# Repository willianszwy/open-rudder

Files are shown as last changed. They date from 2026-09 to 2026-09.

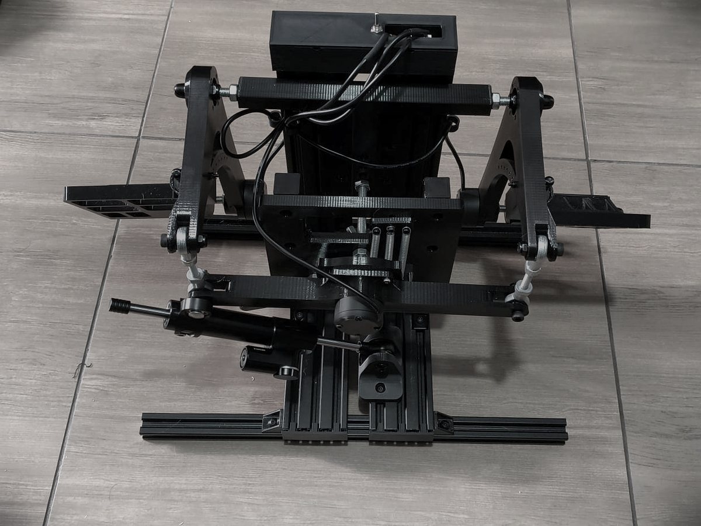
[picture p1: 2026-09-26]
fotos/pedal-cima.jpg

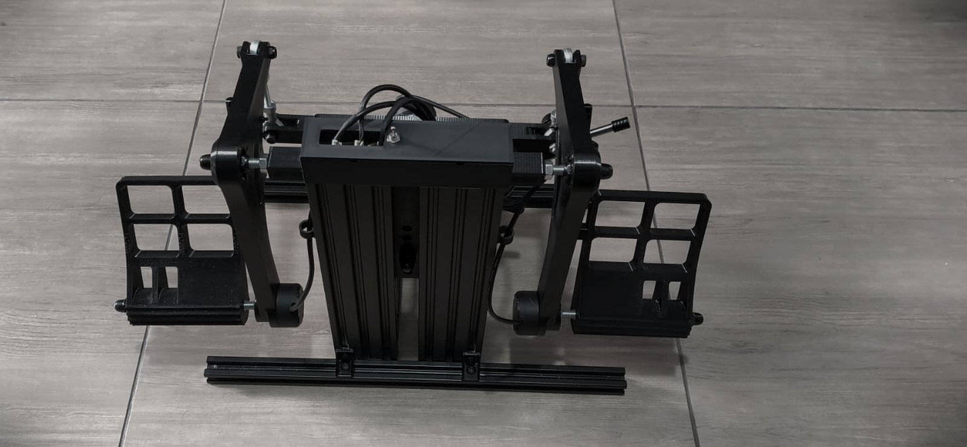
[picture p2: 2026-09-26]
fotos/pedal-frente.jpg

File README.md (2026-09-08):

# Open Rudder

Pedal de leme **pendular** para simulação de voo, com sensor magnético sem contato.
Eletrônica, firmware e calibrador abertos.

O ângulo é lido por um **AS5600** (Hall, 12 bits, absoluto) e um **Pro Micro** publica
o resultado como joystick USB HID — sem potenciômetro, sem contato, sem desgaste no
caminho do sinal.

**→ [Calibrador e esquemas](https://willianszwy.github.io/open-rudder/)** — roda no
navegador, sem instalar nada.

**Estado:** eixo do leme funcionando. Freios de biqueira implementados no firmware,
aguardando montagem mecânica.

## Eixos

| Eixo HID | Fonte | Faixa | Estado |
|---|---|---|---|
| **Rz** | leme | −16383 … +16383 | funcionando |
| **X** | freio de biqueira esquerdo | 0 … 4095 | firmware pronto, mecânica pendente |
| **Y** | freio de biqueira direito | 0 … 4095 | firmware pronto, mecânica pendente |

Rz é o eixo que DCS, MSFS e X-Plane reconhecem direto como leme.

## Arquivos

```
firmware/open_rudder/     firmware principal (leme + 2 freios, USB HID)
firmware/as5600_angle/    sketch mínimo de diagnóstico do sensor
web/calibrador.html       calibrador por Web Serial (Chrome/Edge)
hardware/ligacao.svg      diagrama de ligação
hardware/perfurada.svg    layout da placa perfurada (imprimível 1:1)
hardware/diagrama.html    as duas folhas acima, prontas para imprimir
```

## Eletrônica

O endereço I²C do AS5600 é **fixo em 0x36 e não é programável**, então os três sensores
não coexistem no mesmo barramento. Por isso o **TCA9548A**: cada sensor fica isolado em
um canal, e o firmware chaveia entre eles.

Diagrama de ligação

Detalhes de montagem, capacitores, cabeamento e o layout da placa estão em
`hardware/diagrama.html` — abra no navegador e imprima: a folha da perfurada sai em
tamanho real e serve de gabarito.

> **Tensão:** o AS5600 tem dois modos de alimentação — 5 V pelo pino VDD5V (LDO interno)
> ou 3,3 V pelo VDD3V3. Com módulos de 5 V, o barramento inteiro roda no VCC do Pro Micro
> e nenhum regulador é necessário. Confirme qual variante são os seus antes de ligar:
> num módulo de 3,3 V, 5 V ultrapassa o limite e queima.

### Lista de material (só a eletrônica)

| Item | Qtd | ~R$ |
|---|-----|-----|
| Pro Micro (ATmega32U4, USB HID nativo) | 1 | 35 |
| Módulo AS5600 | 3 | 75 |
| Ímã diametral Ø6×2,5 mm | 3 | 24 |
| Multiplexador I²C TCA9548A (módulo HW-617) | 1 | 12 |
| Placa perfurada 7×9 cm, conectores, cabo par trançado | — | 25 |
| **Total** | | **~R$ 170** |

O ímã tem que ser **diametral** (magnetizado de lado a lado, não axial), centrado no
eixo, a 0,5–3 mm da face marcada do chip.

## Firmware

Precisa da biblioteca [Joystick](https://github.com/MHeironimus/ArduinoJoystickLibrary)
(2.1.1+). Placa: Arduino Micro / Leonardo (ou SparkFun Pro Micro, se você tiver o pacote
instalado).

```bash
arduino-cli compile --fqbn arduino:avr:micro firmware/open_rudder
arduino-cli upload -p COM5 --fqbn arduino:avr:micro firmware/open_rudder
```

Como funciona:

- **Round-robin de 1 kHz** pelos canais do mux — 333 Hz por eixo, de sobra para um pedal.
- **Calibração por eixo na EEPROM**: zero, batentes, inversão, deadzone e expo.
- O zero é resolvido em coordenadas relativas com wrap em ±2048, então **o centro pode
  cair em qualquer ponto do giro** do ímã — não importa como o ímã ficou na montagem.
- **Filtro EMA** (α = 0,35) mata o jitter de ±1 count sem atraso perceptível.
- **Sem o TCA9548A ligado**, cai sozinho para o modo de 1 sensor (só o leme) — dá para
  montar por partes.

Com cabo longo até as biqueiras, se aparecer `sem resposta no eixo`, baixe `I2C_CLOCK`
para `100000` no topo do sketch.

## Calibração

Sem calibrar, o eixo não significa nada: o AS5600 mede 0–360° absolutos e o centro do
seu pedal cai num ponto arbitrário desse círculo.

1. Abra **https://willianszwy.github.io/open-rudder/** e clique em *Calibrador*.
2. **Conectar** e escolha a porta do Arduino.
3. Leme: Centro → Batente esquerdo → Batente direito. Freios: Repouso → Fundo.
4. **Gravar na EEPROM**.

A página mostra os três eixos ao vivo, o status dos ímãs (AGC) e onde o curso útil cai
no giro completo do sensor. Detalhes em `web/README.md`.

> A Web Serial API só funciona em **Chrome ou Edge** e em contexto seguro. O site é
> HTTPS, então serve; abrir o HTML direto pelo Explorer (`file://`) não. Para rodar
> offline, use o `web/servir.bat`, que sobe um servidor local.

## Mecânica

Arquitetura **pendular**: a barra do pedal gira sobre rolamentos e o **ímã diametral fica
na ponta da barra**, coaxial com o eixo de giro. O AS5600 fica fixo de frente para o ímã,
sem encostar em nada — o sensor não faz parte do caminho mecânico, só olha para ele.

O retorno é por **mola**: pisar comprime a mola, que devolve o pedal à posição inicial.
Enquanto você pisa, o AS5600 vai lendo o ângulo continuamente.

Três consequências práticas disso:

- **A posição de repouso da mola é o zero elétrico.** É ela que você captura no passo
  *Centro* da calibração. Se a mola ceder com o tempo, basta capturar o Centro de novo e
  regravar: os batentes são medidos em relação ao zero, então continuam válidos.
- **Alinhamento manda na linearidade.** O ímã precisa estar centrado no eixo de giro, e o
  chip centrado no ímã. Descentralização radial distorce o ângulo lido — e distorce de
  forma que a calibração de pontas não corrige, porque o erro varia ao longo do curso.
- **Distância ímã–chip entre 0,5 e 3 mm.** Confira pelo AGC no calibrador: perto do meio
  da escala é o ideal. Muito baixo significa ímã perto demais, sem margem para saturar.

Restrições que o sensor impõe ao projeto mecânico:

- **Freios:** mire **10–15° de curso** no pivô da biqueira. O AS5600 dá 0,088° por count,
  então 10° ≈ 115 counts — abaixo disso a dosagem fica granulada.
- **Leme:** o AS5600 entrega 4096 counts na volta inteira, então o curso útil é a fração
  do giro que o pedal realmente percorre. Para ±17°, são ~380 counts no curso total —
  equivalente a um potenciômetro de 9 bits. Suficiente, mas é o teto de resolução.

*A documentar:* curso real em graus, dimensões da barra, rolamentos e a mola de retorno.

## Licença

*A definir.*

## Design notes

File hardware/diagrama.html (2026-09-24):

# Open Rudder — diagrama de ligação

Pro Micro (ATmega32U4) · TCA9548A em 0x70 · 3× AS5600 em 0x36, um por canal

Diagrama de ligação: Pro Micro, TCA9548A e três AS5600

Notas de montagem

1. * Alimentação: 5 V direto do Pro Micro. O AS5600 tem dois modos — pelo pino VDD5V (4,5–5,5 V, com LDO interno) ou pelo VDD3V3 (3,0–3,6 V). Os módulos de 5 V rodam no VCC do Pro Micro sem regulador nenhum, e o TCA9548A aceita até 5,5 V. Só se os seus módulos forem da variante 3,3 V é que entra um AMS1117-3.3 alimentado pelo VCC — nesse caso 5 V passa dos 3,6 V do modo e queima o sensor.
2. DIR de cada sensor vai ao GND — define o sentido horário como ângulo crescente. Deixar flutuando dá leitura errática.
3. Pull-ups. Os módulos AS5600 já trazem os deles, e cada canal do mux é isolado, então não precisa somar nada. O firmware desliga os pull-ups internos do ATmega32U4 (que são de 5 V).
4. 100 nF entre VCC e GND junto de cada conector, e 10 µF na entrada de alimentação da placa.
5. Cabo até as biqueiras: par trançado (CAT5 serve) — torça SDA com GND e SCL com VCC. Se aparecer sem resposta no eixo, baixe I2C_CLOCK para 100000 no firmware.
6. Etiquete os três conectores. Os sensores são idênticos; trocar dois de lugar troca os eixos sem dar erro nenhum.

# Open Rudder — layout na placa perfurada

Placa 7×9 cm · grade 26×31 furos a 2,54 mm · vista pelo lado dos componentes. Para imprimir 1:1: Ctrl+P, escala 100%, sem “ajustar à página”, e confira a régua abaixo.

Layout dos componentes na placa perfurada de 26 por 31 furos

Régua de conferência — só vale na folha impressa. Meça: se não der 50 mm exatos, a escala da impressão está errada e o gabarito não serve.

Ordem de montagem sugerida

1. Solde primeiro os dois barramentos (fio rígido nu nas colunas B e D, de ponta a ponta).
2. Depois os soquetes fêmea do Pro Micro — nunca solde a placa direto: você ainda precisa do duplo-toque no RESET para gravar.
3. Mux, conectores, capacitores. Por último os fios finos de sinal, pelo lado do cobre.
4. Antes de plugar qualquer sensor: ligue o USB e meça o trilho de alimentação. Ele deve bater com o modo dos seus módulos: 5 V para os de VDD5V, 3,3 V para os de VDD3V3.

O layout é gerado por gerar_perfurada.py — mexa nos blocos lá e rode o script, não edite o SVG na mão. A grade assume 26×31 furos; com outra contagem os blocos deslizam à vontade e a netlist do diagrama acima não muda.

# Open Rudder — layout na placa de tiras

Alternativa à folha acima, para placa estilo protoboard: linhas horizontais de 5 furos separadas por dois trilhos verticais centrais. Os trilhos viram GND (F) e VCC (G), e os conectores montam a cavalo — os dois pinos do meio caem direto na alimentação. Desenho esquemático, não 1:1: localize tudo pelas linhas numeradas da placa.

Layout na placa de tiras: Pro Micro e TCA9548A a cavalo sobre os trilhos centrais de GND e VCC

O que muda em relação à placa lisa

1. A pinagem do chicote passa a ser SDA · GND · VCC · SCL — energia no meio. É o que faz os dois pinos centrais do JST caírem nos trilhos sem jumper nenhum. A tabela da folha seguinte ainda está na ordem antiga; só vale uma das duas.
2. Não existe mais barramento de fio rígido para soldar: os trilhos já são de fábrica. Confira só se eles são contínuos de ponta a ponta — em algumas placas vêm partidos no meio, e aí precisa de um jumper unindo as metades.
3. Encaixe a seco o Pro Micro e o mux antes de soldar. Nenhuma perna pode cair nas colunas F ou G: pino no trilho é curto de VCC em GND direto pela USB.
4. Jumpers de força são de um furo só: GND sai pela metade esquerda (linhas 5 e 20), VCC pela direita (linha 6), e A0/A1/A2 vão ao GND nas linhas 24–26. O único que pula um trilho é o VIN do mux, na linha 19.
5. O HW-617 é assimétrico: os canais 0 e 1 saem do mesmo lado dos pinos de controle; o canal 2 sai do lado oposto, que corre de baixo para cima (SD2/SC2 embaixo, SC7 no topo). Por isso um fio por sensor cruza os trilhos — o SCL nos canais 0 e 1, o SDA no canal 2.
6. Os pinos SD3…SC7 ficam enfiados em tiras que não usamos. Deixe essas linhas livres.
7. O RST do mux costuma ter pull-up no próprio módulo. Se o seu não tiver, jumper de RST para VCC.
8. Capacitores: são dois, nas linhas 15 e 16, cada um na sua linha e os dois atravessando F e G — os trilhos já os põem em paralelo. Os 100 nF dos sensores são à parte, um em cada AS5600, como mostra o diagrama de ligação. O 100 nF daqui é cerâmico (MLCC X7R, 50 V). O 10 µF de bulk tanto faz — eletrolítico de alumínio 25 V dá e sobra para os ~80 mA deste circuito; sólido (polímero) só paga uma margem que aqui não se usa. Se for eletrolítico, atenção: os dois trilhos ficam colados, então a tarja (−) vai em F = GND e o positivo em G. Um cerâmico de 10 µF X7R/X5R 25 V elimina esse risco — não tem lado.

Gerado por gerar_tiras.py — mexa nas constantes do topo e rode o script, não edite o SVG na mão. A grade assumida é 12 colunas × 40 linhas com tiras de 5 furos; com outra contagem, ajuste COLS/ROWS e os blocos deslizam junto. A netlist do diagrama de ligação não muda.

# Open Rudder — chicote do sensor

Três chicotes iguais, um por sensor. Cabo UL2464 de 4 núcleos, 26 AWG · conector JST-XH de 4 vias só do lado da placa.

Chicote: módulo AS5600, cabo com laço de folga e conector JST-XH

### Ligação, via a via

Via do JST-XH | Função | Pino no módulo | Cor do seu cabo
1 | VCC | VCC (5 V)
2 | GND | GND (+ jumper para DIR)
3 | SCL | SCL
4 | SDA | SDA

Preencha a última coluna à caneta antes de cortar o primeiro cabo: as cores do UL2464 não seguem convenção nenhuma, e com a capa já removida é fácil inverter SDA e SCL. A ordem das vias 1–4 é convenção nossa; a do módulo é o que estiver na serigrafia dele, que muda de fabricante para fabricante.

Montagem

1. Meça o cabo com o pedal no fim do curso, não em repouso. Os dois chicotes dos freios acompanham a biqueira: cortados no comprimento de repouso, ficam esticados na deflexão máxima e arrancam a solda. Meça na posição mais longa e ainda acrescente o laço.
2. DIR vai ao GND no próprio módulo, com um jumper curto. Não gaste uma via do conector com isso.
3. Solda no lado do sensor, conector só no lado da placa. A ponta que flexiona é a que falha; um conector ali seria mais dois contatos no lugar errado. Se um sensor pifar, você troca o conjunto sensor + cabo inteiro.
4. Termorretrátil sobre as quatro soldas, e um segundo pedaço maior por cima de todas, envolvendo a entrada do cabo.
5. Abraçadeira presa à estrutura a uns 3 cm da solda. É ela que segura o esforço: sem isso, a solda vira o ponto de dobra e trinca. É assim que morrem 90% desses cabos.
6. Teste de arranque antes do chicote real: crimpe um terminal num pedaço do mesmo cabo e puxe firme. O fio tem que arrebentar antes de sair do terminal. Se ele desliza, o ninho do alicate está grande demais — troque de ninho e repita.
7. Etiquete os três (leme / esq / dir). São idênticos, e trocar dois de lugar troca os eixos sem dar erro nenhum.

Conferência final: abra o calibrador e pise em cada pedal olhando qual eixo se move. Chicote trocado aparece em cinco segundos, antes de parafusar qualquer coisa.

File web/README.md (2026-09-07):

# Calibrador web — Open Rudder

Página que conversa com o Pro Micro pela porta serial (Web Serial API) para
visualizar o eixo e calibrar o pedal sem abrir o Serial Monitor.

## Versão hospedada

**https://willianszwy.github.io/open-rudder/** — o GitHub Pages serve por HTTPS, que é
contexto seguro, então a Web Serial funciona direto. Não precisa de servidor local.

O `servir.bat` abaixo continua útil só para desenvolver offline ou testar alterações
antes de commitar.

## Como usar

1. Grave o sketch `firmware/open_rudder` no Pro Micro.
2. Dê dois cliques em **`servir.bat`** (sobe um servidor local e abre o navegador).
3. Clique em **Conectar** e escolha a porta do Arduino na lista do Chrome.

> A Web Serial API só funciona em **Chrome ou Edge** e só em contexto seguro
> (`localhost` ou HTTPS). Abrir o `calibrador.html` direto pelo Explorer
> (`file://`) faz o botão Conectar falhar — por isso o `servir.bat`.

Para parar o servidor: `Ctrl+C` na janela preta.

## Calibração

1. **Centro** — pedais soltos, clique em Capturar.
2. **Batente esquerdo** — pise a fundo à esquerda, Capturar.
3. **Batente direito** — pise a fundo à direita, Capturar.
4. **Gravar na EEPROM**.

Se os lados saírem trocados, clique em *Inverter lados* e repita os passos 2 e 3.
Enquanto houver mudança não gravada, aparece o aviso "alterações não gravadas" —
sem clicar em Gravar, tudo volta ao estado anterior no próximo boot.

## O que a página mostra

- **Eixo do leme** — deflexão em graus, saída em %, valor HID (±16383) e leitura
  bruta do AS5600 (0–4095).
- **Posição no giro do ímã** — onde o centro e o curso útil caem no círculo
  completo do sensor. Útil pra ver que só ~9% do giro é usado (±17°) e que o
  centro pode estar em qualquer ponto.
- **Ajuste de resposta** — deadzone e expo, com a curva desenhada e um ponto
  amarelo mostrando onde você está nela em tempo real.
- **Ímã** — status (OK / fraco / forte / ausente) e AGC. Use na montagem pra
  achar a distância certa entre o ímã e o chip.

## Protocolo

O firmware emite duas linhas de máquina (25 Hz, só depois do comando `>`):

```
D,raw,rel,eixo,statusIma,agc      statusIma: 0=ok 1=sem ima 2=fraco 3=forte 4=erro
C,centro,minRel,maxRel,invert,deadzone,expo
```

Comandos aceitos (um por linha): `c` `l` `r` `i` `w` `e` `?` `s` `p` `>` `<`,
mais `d<n>` (deadzone) e `x<n>` (expo). Qualquer outra linha é texto humano —
a página joga no painel de mensagens.

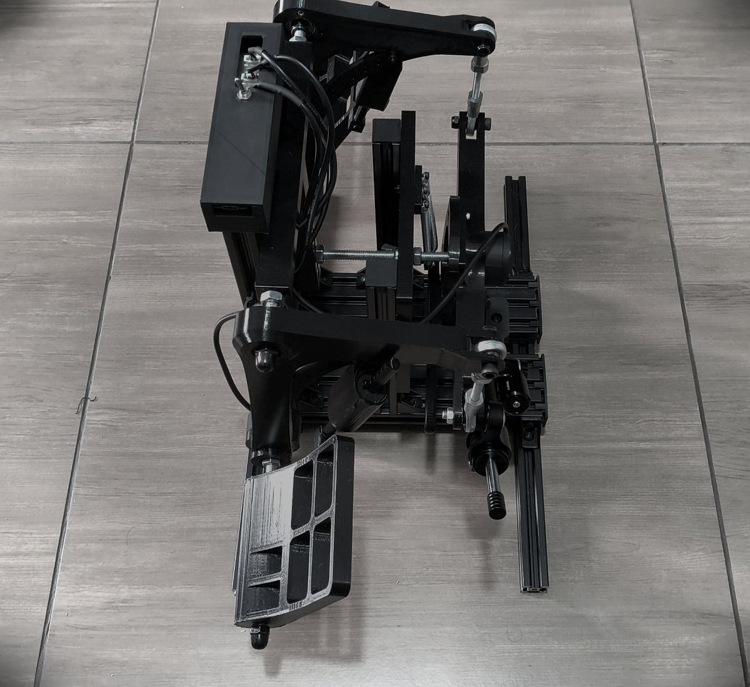
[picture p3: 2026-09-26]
fotos/pedal-lado.jpg

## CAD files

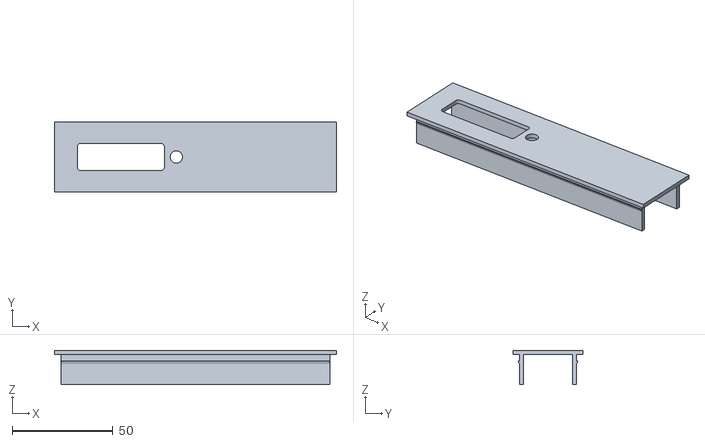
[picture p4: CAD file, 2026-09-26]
hardware/stl/case_tampa.stl
140.0 x 34.7 x 17.0

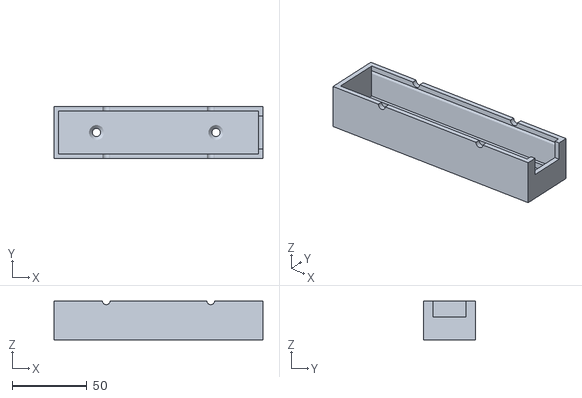
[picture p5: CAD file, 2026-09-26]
hardware/stl/case_base.stl
140.0 x 34.7 x 26.1

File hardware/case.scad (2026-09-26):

// case.scad — caixa da placa de controle do Open Rudder
//
// Abriga a placa de tiras de 129 × 28 mm com o Pro Micro, o TCA9548A e os três
// conectores dos sensores. Duas peças: bandeja e tampa, sem parafuso nenhum
// prendendo a placa.
//
// POR QUE A PLACA NÃO É PARAFUSADA. Placa de tiras não vem com furo de fixação,
// e furar depois de montada é onde se corta uma trilha sem perceber. Aqui ela
// apenas DESCE na bandeja e pousa num ressalto corrido; a tampa traz duas
// nervuras que descem até a face de cima e a prensam contra esse ressalto. A
// placa fica presa pelas duas bordas longas, sem furo, sem espaçador e sem
// parafuso passando perto de cobre.
//
// O preço disso é que os APOIO mm mais externos de cada borda ficam cobertos
// pelo ressalto embaixo e pela nervura em cima. A fileira de furos mais externa
// precisa estar livre de solda alta desse lado — se tiver, reduza APOIO ou
// levante H_SOLDA.
//
// AS NERVURAS SÓ EXISTEM NAS LATERAIS. Nas duas pontas a tampa é vazada de
// propósito: é por onde sai o cabo USB. Nervura correndo na ponta fecharia
// justamente essa passagem.
//
// OS CHICOTES SAEM POR CIMA, pela tampa, e não pela parede. O JST-XH é de
// entrada vertical, então o cabo já aponta para cima; desviá-lo 90° para uma
// fenda lateral colocaria a dobra em cima da solda. Os rasgos são largos o
// bastante para a carcaça do conector atravessar, de modo que a tampa sai sem
// desplugar nada.
//
// FURO DE ACESSO AO RESET. Não é conveniência: este Pro Micro não enumera no
// plug a frio — o Windows acusa falha de descritor e a placa só aparece depois
// de um toque no RESET. Enquanto ele não for trocado, o botão precisa estar
// alcançável com a caixa fechada, senão cada boot do PC vira desmontagem.
// Confira RESET_X contra a sua montagem antes de imprimir; a cota é medida do
// centro da caixa.
//
// FIXAÇÃO NO PERFIL. Dois furos retos na linha de centro do fundo, para
// castanha de 2020. Ficam na linha de centro porque a caixa é mais larga que o
// perfil: orelha lateral jogaria o furo para fora da fenda.
//
// O parafuso entra de dentro para fora, então a cabeça fica alojada sob a placa
// e consome parte de H_SOLDA. O furo é reto de propósito — escareado na face
// externa não alojaria nada e só afinaria o fundo. Se a cabeça não couber no
// vão, ESCAREADO = "interno" afunda ela no fundo pela face de cima.
//
// Imprima as duas peças deitadas, sem suporte: a bandeja com a boca para cima,
// a tampa com as nervuras para cima.
//
// Precisa do OpenSCAD 2021.01 ou mais novo.


/* ------------------------------------------------------------- parâmetros */

PECA = "ambas";    // "base" | "tampa" | "ambas" (ambas = vista de montagem)

PLACA_C = 129;     // mm, comprimento da placa
PLACA_L = 28;      // mm, largura
PLACA_E = 1.6;     // mm, espessura do laminado
// FOLGA DE IMPRESSÃO. Todo encaixe entre peça impressa e peça impressa — ou
// entre peça impressa e componente — precisa dela: furo sai menor que o
// nominal, saliência sai maior, e encaixe modelado justo simplesmente não
// entra. A primeira impressão provou isso em três pontos de uma vez.
//
// Aplicada POR FACE. Um bolso para um corpo de 6,0 mm vira 6,0 + 2*TOL.
TOL = 0.2;         // mm, folga por face

FOLGA   = 0.35;    // mm, folga por lado na LARGURA (justo: é o que centra)
FOLGA_C = 1.0;     // mm, folga por ponta no COMPRIMENTO

// O USB-C do Pro Micro avança além da borda do laminado. Essa sobra é só de um
// lado, então a cavidade cresce SÓ na ponta do USB — folgar as duas pontas
// desperdiçaria comprimento e ainda deixaria a placa jogar dentro da caixa.
//
// x = 0 continua sendo o CENTRO DA PLACA, não o da caixa: é a referência em que
// você mede tudo (SAIDAS, RESET_X, FUROS, ARDUINO_Y). Quem fica assimétrico em
// torno dela é o case.
USB_SAI = 3.0;     // mm, quanto o conector avança além da borda

H_SOLDA = 3.5;     // mm, vão sob a placa para as pernas soldadas
// 18 e não 16: esta é a única cota que não foi medida, e o erro é assimétrico.
// Para baixo, a tampa não fecha e as duas peças vão fora. Para cima, o custo é
// só altura — as nervuras ficam na borda da placa, onde não há componente, e
// alcançam a face dela de qualquer forma. Vale pagar 2 mm pelo seguro.
//
// Pilha esperada: soquete 8,5 + plaquinha 1,6 + USB-C 3,2 = ~13,3 mm.
// Altura livre sobre a placa. Com o interruptor de alavanca na tampa ela deixa
// de ser escolha e vira consequência: o corpo dele desce RESET_CORPO a partir
// da tampa, e embaixo do ponto escolhido há ALT_SOB_RESET de componente. A
// conta se faz sozinha abaixo, em H_COMP.
H_COMP_MIN   = 18;     // mm, o que já bastava para a placa sozinha
ALT_SOB_RESET = 10.1;  // mm, altura do que está sob o interruptor — aqui o mux
                       //     em soquete (8,5 + 1,6). Medido na foto: o mux vai
                       //     de x=-9,3 a +22,7, e RESET_X=-3 cai sobre ele.

// Pro Micro e mux ficam em soquete, para poderem sair sem dessoldar. Isso
// levanta o conector USB: ele não está rente à placa, e sim H_SOQUETE acima
// dela. O rasgo do USB é posicionado a partir daqui — desenhado rente à placa,
// ele ficaria inteiro abaixo do conector.
H_SOQUETE = 8.5;   // mm, altura do soquete fêmea
H_MODULO  = 1.6;   // mm, espessura da plaquinha do Pro Micro
H_USB     = 3.0;   // mm, altura da carcaça do conector USB
APOIO   = 2.0;     // mm, quanto o ressalto avança sob a borda da placa

// As nervuras da tampa NÃO descem até a face da placa. Elas desceriam bem em
// cima das bordas, que é justamente por onde correm os fios — e foi isso que
// impediu a tampa de fechar na primeira montagem, faltando ~2 mm.
//
// Subir H_COMP não resolveria: a tampa sobe e as nervuras sobem junto, e elas
// continuam alcançando a mesma altura sobre a placa. O que resolve é encurtar.
//
// O preço é que a placa deixa de ser prensada e ganha esta folga vertical. Ela
// continua presa de lado pelas paredes e apoiada nos ressaltos; o que some é o
// aperto. Se chacoalhar, o caminho não é alongar a nervura de volta — é pôr um
// calço de espuma na tampa, que se acomoda aos fios.
NERVURA_FOLGA = 3.0;  // mm, quanto a nervura para antes da placa

T_PAREDE = 3.0;    // mm, parede lateral — 3 é o padrão do usuário, para a
                   //     parede aguentar castanha/porca embutida
T_FUNDO  = 3.0;    // mm, fundo — grosso para escarear a cabeça do parafuso
T_TAMPA  = 2.0;    // mm, tampa

// --- encaixe da tampa (friso nas nervuras, sulco na parede)
FRISO_P = 0.7;     // mm, quanto o friso avança
FRISO_H = 1.4;     // mm, altura do friso
FRISO_Z = 4.0;     // mm, do topo da parede até o topo do friso
FRISO_F = TOL;     // mm, folga no sulco

// --- aberturas. X é medido do centro da caixa, ao longo do comprimento.
// O Pro Micro não está centrado na largura da placa, então o rasgo do USB e o
// furo do RESET seguem o EIXO DELE, não o da placa. Meça do centro da placa até
// o centro do Pro Micro e ponha aqui, com sinal.
// Medido direto no que importa: 12,2 mm da borda direita da placa até o CENTRO
// do conector USB. Daí 28,0 - 12,2 = 15,8 da borda esquerda, e o descentramento
// é 15,8 - 14,0 = 1,8 mm para o lado direito.
//
// Essa é a cota boa. As folgas de borda medidas antes (8,4 e 4,0) davam 2,2 e
// não fechavam com a largura nominal do Pro Micro — medir até o centro do
// conector não passa por suposição nenhuma sobre o módulo.
//
// O sinal positivo aponta para a borda direita. Se o rasgo sair espelhado na
// peça impressa, troque o sinal: é a única coisa aqui que depende de qual lado
// você chamou de direito.
ARDUINO_Y = 1.8;   // mm

// Largura generosa e CENTRADA NA PLACA, em vez de justa e centrada no Pro
// Micro. A primeira impressão saiu com o rasgo visivelmente torto, e a causa
// mais provável é o sinal de ARDUINO_Y: qual borda é "direita" dependeu da
// minha interpretação de uma medida em texto, e sinal trocado dobra o erro
// para 3,6 mm.
//
// Com 22 mm o rasgo cobre o conector nas DUAS hipóteses de sinal — no pior
// caso ele fica entre -6,3 e +2,7, bem dentro dos ±11. Some-se o overmold do
// plugue, que é bem maior que a carcaça metálica.
//
// Se um dia você medir o descentramento real, dá para reapertar: volte USB_Y
// para ARDUINO_Y e USB_L para uns 15.
USB_L = 22;        // mm, largura do rasgo
USB_H = 8 + 2 * TOL;   // mm, altura
USB_Y = 0;         // mm, centrado na placa — ver nota em USB_L
USB_Z = H_SOQUETE + H_MODULO + H_USB / 2;   // mm, centro do conector sobre a placa

// O rasgo do USB sobe até o topo da parede em vez de ser uma janela fechada: em
// soquete o conector fica tão alto que uma janela deixaria menos de 1 mm de
// parede acima dela — uma lasca que não imprime. A tampa apoia em cima e fecha
// a abertura de qualquer jeito. Só feche a janela (false) se aumentar H_COMP o
// bastante para sobrar uns 2,5 mm de material acima do rasgo.
USB_ABERTO = true;
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

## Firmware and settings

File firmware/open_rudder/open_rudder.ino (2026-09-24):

/*
 * Open Rudder - leme + 2 freios de biqueira como joystick USB
 * Arduino Pro Micro (ATmega32U4) + TCA9548A + 3x AS5600
 * Biblioteca Joystick (MHeironimus) 2.1.1
 *
 * POR QUE O MUX: o endereco I2C do AS5600 e fixo em 0x36 e nao e programavel,
 * entao tres sensores nao coexistem no mesmo barramento. O TCA9548A isola cada
 * um em seu canal; o mestre fala com um canal por vez.
 *
 * LIGACAO
 *   Pro Micro          TCA9548A            sensores
 *     SDA (2) --------- SDA    SD0/SC0 ---- AS5600 leme
 *     SCL (3) --------- SCL    SD1/SC1 ---- AS5600 freio esquerdo
 *     VCC    --------- VIN    SD2/SC2 ---- AS5600 freio direito
 *     GND    --------- GND
 *                      A0,A1,A2 -> GND  (endereco 0x70)
 *   Cada AS5600: VCC 5V, GND, DIR em GND.
 *
 * TENSAO: tudo em 5V, sem regulador. O AS5600 tem dois modos - VDD5V (4,5 a
 * 5,5V, com LDO interno) ou VDD3V3 (3,0 a 3,6V); com modulos da variante 5V o
 * barramento inteiro roda no VCC do Pro Micro e o TCA9548A aceita ate 5,5V.
 * Em modulos da variante 3,3V os 5V queimam o sensor.
 *
 * Sem o mux ligado o firmware cai automaticamente para o modo de 1 sensor
 * (so o leme, AS5600 direto no barramento) - da para montar por partes.
 *
 * EIXOS HID
 *   Rz  leme            -16383..16383   (centro no zero)
 *   X   freio esquerdo       0..4095    (repouso no zero)
 *   Y   freio direito        0..4095
 *
 * CURSO MINIMO DOS FREIOS: o AS5600 da 0,088 graus por count. Para um freio
 * com resolucao decente mire 10-15 graus de giro no pivo da biqueira (~115-170
 * counts). Abaixo de ~5 graus a dosagem fica granulada.
 *
 * COMANDOS (uma linha cada). Comandos de eixo levam o numero do eixo na frente:
 *   0=leme  1=freio esq  2=freio dir
 *     0c      centro do leme (pedais soltos)
 *     0l      batente esquerdo        0r   batente direito
 *     1c      repouso do freio esq    1r   freio esq a fundo
 *     2c      repouso do freio dir    2r   freio dir a fundo
 *     0i      inverte os lados do leme
 *     1d4     deadzone do eixo 1 = 4 counts   (sem numero: cicla 0/2/4/8)
 *     0x30    expo do eixo 0 = 30%            (sem numero: cicla 0/15/30/45)
 *   Globais: w grava na EEPROM | e apaga | ? mostra tudo | s status dos imas
 *            p monitor legivel | > < liga/desliga a telemetria da pagina web
 *
 * PROTOCOLO da telemetria (uma linha por eixo, 25 Hz, apos o comando '>'):
 *   D,eixo,raw,rel,valor,statusIma,agc
 *        statusIma: 0=ok 1=sem ima 2=fraco 3=forte 4=erro I2C 5=canal vazio
 *   C,eixo,repouso,minRel,maxRel,invert,deadzone,expo
 *
 * NOTA para regravar: com HID ativo o Pro Micro as vezes nao entra em bootloader
 * sozinho. De dois toques rapidos no RESET e mande o upload na janela de ~8 s.
 */

#include <Wire.h>
#include <EEPROM.h>
#include <Joystick.h>

// ---------------------------------------------------------------- constantes
static const uint8_t MUX_ADDR        = 0x70;
static const uint8_t AS5600_ADDR     = 0x36;
static const uint8_t REG_STATUS      = 0x0B;
static const uint8_t REG_RAW_ANGLE_H = 0x0C;
static const uint8_t REG_AGC         = 0x1B;
static const uint8_t REG_MAGNITUDE_H = 0x1C;

static const uint8_t STATUS_MD = 0x20;
static const uint8_t STATUS_ML = 0x10;
static const uint8_t STATUS_MH = 0x08;

static const uint8_t AXIS_COUNT  = 3;
static const uint8_t AX_RUDDER   = 0;

// Faixa de saida de cada eixo no HID.
static const int32_t RUDDER_RANGE = 16383;   // simetrico: -RANGE..+RANGE
static const int32_t BRAKE_RANGE  = 4095;    // unidirecional: 0..RANGE

// 400 kHz e seguro com os sensores na bancada. Com cabo longo ate as biqueiras
// (>30 cm) o barramento pode ficar marginal: caia para 100000 se aparecer
// "sem resposta no eixo" ou leitura pulando. Mesmo a 100 kHz cada leitura leva
// ~540 us, entao o round-robin de 1 ms continua cabendo.
static const uint32_t I2C_CLOCK = 400000;

static const uint16_t UPDATE_INTERVAL_US = 1000;   // 1 kHz (round-robin: 333 Hz/eixo)
static const uint16_t PRINT_INTERVAL_MS  = 100;
static const uint16_t TELEM_INTERVAL_MS  = 40;     // 25 Hz para a pagina web

// Filtro exponencial: 1.0 = sem filtro, menor = mais suave e mais lento.
static const float EMA_ALPHA = 0.35f;

// Cursos padrao antes de calibrar.
static const int16_t RUDDER_TRAVEL = 194;   // 17 graus
static const int16_t BRAKE_TRAVEL  = 170;   // 15 graus

// Curso minimo aceito numa captura de batente - abaixo disso e engano.
static const int16_t MIN_TRAVEL = 10;

static const uint32_t EEPROM_MAGIC = 0x4D315233UL;   // "Open Rudder v3 (3 eixos)"
static const int      EEPROM_ADDR  = 0;

// ------------------------------------------------------------------- config
struct AxisCal {
  uint16_t restRaw;   // leitura bruta no centro (leme) ou no repouso (freio)
  int16_t  minRel;    // batente negativo - so o leme usa
  int16_t  maxRel;    // batente positivo / fundo do freio
  uint8_t  invert;
  uint8_t  deadzone;
  uint8_t  expo;
};

struct Config {
  uint32_t magic;
  AxisCal  axis[AXIS_COUNT];
};

Config cfg;

// true = eixo bidirecional (leme), false = unidirecional (freio)
inline bool isRudder(uint8_t a) { return a == AX_RUDDER; }

const char *axisName(uint8_t a) {
  return a == 0 ? "leme" : a == 1 ? "freio esq" : "freio dir";
}

// ------------------------------------------------------------------- estado
Joystick_ Joystick(
  JOYSTICK_DEFAULT_REPORT_ID,
  JOYSTICK_TYPE_JOYSTICK,
  0, 0,                          // sem botoes, sem hat
  true,  true,  false,           // X (freio esq), Y (freio dir), Z
  false, false, true,            // Rx, Ry, Rz (leme)
  false, false, false, false, false);

float    filtered[AXIS_COUNT];     // saida normalizada ja filtrada
uint16_t lastRaw[AXIS_COUNT];
bool     present[AXIS_COUNT];      // sensor respondeu no boot
uint8_t  errors[AXIS_COUNT];

bool     muxPresent = false;
uint8_t  rrChannel  = 0;           // canal da vez no round-robin

bool     monitor    = false;
bool     telemetry  = false;
uint32_t lastUpdate = 0;
uint32_t lastPrint  = 0;
uint32_t lastTelem  = 0;

char     cmdBuf[16];
uint8_t  cmdLen = 0;
uint32_t lastCharMs = 0;

// -------------------------------------------------------------- I2C helpers
bool probe(uint8_t addr) {
  Wire.beginTransmission(addr);
  return Wire.endTransmission() == 0;
}

// Abre um unico canal do mux. Sem mux, so o canal 0 "existe".
bool muxSelect(uint8_t ch) {
  if (!muxPresent) return ch == 0;
  Wire.beginTransmission(MUX_ADDR);
  Wire.write((uint8_t)(1 << ch));
  return Wire.endTransmission() == 0;
}

bool readReg8(uint8_t reg, uint8_t &value) {
  Wire.beginTransmission(AS5600_ADDR);
  Wire.write(reg);
  if (Wire.endTransmission(false) != 0) return false;
  if (Wire.requestFrom((uint8_t)AS5600_ADDR, (uint8_t)1) != 1) return false;
  value = Wire.read();
  return true;
}

bool readReg12(uint8_t regHigh, uint16_t &value) {
  Wire.beginTransmission(AS5600_ADDR);
  Wire.write(regHigh);
  if (Wire.endTransmission(false) != 0) return false;
  if (Wire.requestFrom((uint8_t)AS5600_ADDR, (uint8_t)2) != 2) return false;
  uint8_t hi = Wire.read();
  uint8_t lo = Wire.read();
  value = (((uint16_t)hi << 8) | lo) & 0x0FFF;
  return true;
}

// Le o angulo bruto do sensor de um eixo, cuidando do mux.
bool readAngle(uint8_t a, uint16_t &raw) {
  if (!muxSelect(a)) return false;
  return readReg12(REG_RAW_ANGLE_H, raw);
}

// 0=ok 1=sem ima 2=fraco 3=forte 4=erro I2C 5=canal vazio
uint8_t magnetCode(uint8_t a) {
  if (!present[a]) return 5;
  if (!muxSelect(a)) return 4;
  uint8_t status = 0;
  if (!readReg8(REG_STATUS, status)) return 4;
  if (!(status & STATUS_MD))         return 1;
  if (status & STATUS_ML)            return 2;
  if (status & STATUS_MH)            return 3;
  return 0;
}

uint8_t readAgc(uint8_t a) {
  uint8_t agc = 0;
  if (present[a] && muxSelect(a)) readReg8(REG_AGC, agc);
  return agc;
}

// ------------------------------------------------------------------ dominio
// Posicao relativa ao repouso, resolvendo a volta do circulo: o resultado fica
// sempre em -2048..2047, entao o zero pode cair em qualquer ponto do giro.
int16_t relativeToRest(uint8_t a, uint16_t raw) {
  int16_t rel = (int16_t)raw - (int16_t)cfg.axis[a].restRaw;
  if (rel >  2048) rel -= 4096;
  if (rel < -2048) rel += 4096;
  return rel;
}

// Converte counts relativos na saida normalizada do eixo:
//   leme  -> -1..1, com os dois batentes escalados separadamente
//   freio ->  0..1, so o sentido de acionamento
float normalize(uint8_t a, int16_t rel) {
  const AxisCal &c = cfg.axis[a];
  if (c.invert) rel = -rel;

  int16_t dz = c.deadzone;
  if (!isRudder(a)) {
    // Freio: qualquer coisa antes da deadzone e repouso. Sem isso, um drift de
    // 2 counts vira freio arrastando o tempo todo.
    if (rel <= dz) return 0.0f;
    int16_t span = c.maxRel - dz;
    if (span <= 0) return 0.0f;
    float n = (float)(rel - dz) / span;
    return n > 1.0f ? 1.0f : n;
  }

  if (rel > -dz && rel < dz) return 0.0f;
  rel += (rel > 0) ? -dz : dz;

  float n;
  if (rel >= 0) {
    int16_t span = c.maxRel - dz;
    n = (span > 0) ? (float)rel / span : 0.0f;
  } else {
    int16_t span = -c.minRel - dz;   // minRel e negativo
    n = (span > 0) ? (float)rel / span : 0.0f;
  }

  if (n >  1.0f) n =  1.0f;
  if (n < -1.0f) n = -1.0f;
  return n;
}

// Expo: suaviza o inicio do curso e mantem o ganho no fim. e=0 -> linear.
float applyExpo(uint8_t a, float n) {
  uint8_t e8 = cfg.axis[a].expo;
  if (e8 == 0) return n;
  float e = e8 / 100.0f;
  return (1.0f - e) * n + e * n * n * n;
}

void pushToHid(uint8_t a) {
  float v = filtered[a];
  switch (a) {
    case 0: Joystick.setRzAxis((int32_t)(v * RUDDER_RANGE)); break;
    case 1: Joystick.setXAxis((int32_t)(v * BRAKE_RANGE));   break;
    case 2: Joystick.setYAxis((int32_t)(v * BRAKE_RANGE));   break;
  }
}

int32_t hidValue(uint8_t a) {
  return (int32_t)(filtered[a] * (isRudder(a) ? RUDDER_RANGE : BRAKE_RANGE));
}

// -------------------------------------------------------------- persistencia
void loadDefaults() {
  cfg.magic = EEPROM_MAGIC;
  for (uint8_t a = 0; a < AXIS_COUNT; a++) {
    AxisCal &c = cfg.axis[a];
    c.restRaw  = 0;
    c.invert   = 0;
    c.expo     = 0;
    if (isRudder(a)) {
      c.minRel   = -RUDDER_TRAVEL;
      c.maxRel   =  RUDDER_TRAVEL;
      c.deadzone = 0;
    } else {
      c.minRel   = 0;
      c.maxRel   = BRAKE_TRAVEL;
      c.deadzone = 4;      // freio sempre com folga no repouso
    }
  }
}

bool configValid() {
  if (cfg.magic != EEPROM_MAGIC) return false;
  for (uint8_t a = 0; a < AXIS_COUNT; a++) {
    if (cfg.axis[a].maxRel < MIN_TRAVEL) return false;
    if (isRudder(a) && cfg.axis[a].minRel > -MIN_TRAVEL) return false;
  }
  return true;
}

void loadConfig() {
  EEPROM.get(EEPROM_ADDR, cfg);
  if (!configValid()) {
    loadDefaults();
    Serial.println(F("EEPROM vazia/invalida - usando padrao. Calibre e grave com 'w'."));
  }
}

void saveConfig() {
  cfg.magic = EEPROM_MAGIC;
  EEPROM.put(EEPROM_ADDR, cfg);
  Serial.println(F(">> calibracao gravada na EEPROM"));
}

// -------------------------------------------------------------- saida serial
void sendConfigLine(uint8_t a) {
  const AxisCal &c = cfg.axis[a];
  Serial.print(F("C,"));
  Serial.print(a);          Serial.print(',');
  Serial.print(c.restRaw);  Serial.print(',');
  Serial.print(c.minRel);   Serial.print(',');
  Serial.print(c.maxRel);   Serial.print(',');
  Serial.print(c.invert);   Serial.print(',');
  Serial.print(c.deadzone); Serial.print(',');
  Serial.println(c.expo);
}

void sendAllConfig() {
  for (uint8_t a = 0; a < AXIS_COUNT; a++) sendConfigLine(a);
}

void sendTelemetry() {
  for (uint8_t a = 0; a < AXIS_COUNT; a++) {
    Serial.print(F("D,"));
    Serial.print(a);                       Serial.print(',');
    Serial.print(lastRaw[a]);              Serial.print(',');
    Serial.print(relativeToRest(a, lastRaw[a])); Serial.print(',');
    Serial.print(hidValue(a));             Serial.print(',');
    Serial.print(magnetCode(a));           Serial.print(',');
    Serial.println(readAgc(a));
  }
}

void printConfig() {
  Serial.print(F("mux: "));
  Serial.println(muxPresent ? F("TCA9548A em 0x70") : F("ausente (modo 1 sensor)"));
  for (uint8_t a = 0; a < AXIS_COUNT; a++) {
    const AxisCal &c = cfg.axis[a];
    Serial.print('[');  Serial.print(a); Serial.print(F("] "));
    Serial.print(axisName(a));
    Serial.print(present[a] ? F("  ") : F(" (SEM SENSOR) "));
    Serial.print(F(" repouso=")); Serial.print(c.restRaw);
    if (isRudder(a)) { Serial.print(F(" esq=")); Serial.print(c.minRel); }
    Serial.print(F(" max="));     Serial.print(c.maxRel);
    Serial.print(F(" curso="));
    Serial.print((c.maxRel - (isRudder(a) ? c.minRel : 0)) * 360.0f / 4096.0f, 1);
    Serial.print(F("deg inv="));  Serial.print(c.invert);
    Serial.print(F(" dz="));      Serial.print(c.deadzone);
    Serial.print(F(" expo="));    Serial.print(c.expo);
    Serial.println('%');
  }
}

void printMagnetStatus() {
  for (uint8_t a = 0; a < AXIS_COUNT; a++) {
    uint8_t code = magnetCode(a);
    Serial.print('[');  Serial.print(a); Serial.print(F("] "));
    Serial.print(axisName(a)); Serial.print(F(": "));
    switch (code) {
      case 0: Serial.print(F("ima OK"));            break;
      case 1: Serial.print(F("SEM IMA detectado")); break;
      case 2: Serial.print(F("ima FRACO"));         break;
      case 3: Serial.print(F("ima FORTE"));         break;
      case 5: Serial.print(F("canal vazio"));       break;
      default: Serial.print(F("erro I2C"));         break;
    }
    if (code <= 3) {
      uint16_t magnitude = 0;
      Serial.print(F(" | AGC=")); Serial.print(readAgc(a));
      if (muxSelect(a) && readReg12(REG_MAGNITUDE_H, magnitude)) {
        Serial.print(F(" | MAG=")); Serial.print(magnitude);
      }
    }
    Serial.println();
  }
}

// ---------------------------------------------------------------- comandos
// Comando de eixo: "<n><letra>[valor]"  ex.: 0c, 1r, 2d4, 0x30
// Comando global:  "<letra>"            ex.: w, e, ?, s, p, >, <
void handleAxisCommand(uint8_t a, char c, bool hasArg, int arg) {
  AxisCal &cal = cfg.axis[a];
  int16_t  raw = lastRaw[a];
  bool changed = true;

  switch (c) {
    case 'c':
      cal.restRaw = raw;
      Serial.print(F(">> ")); Serial.print(axisName(a));
      Serial.print(isRudder(a) ? F(": centro = ") : F(": repouso = "));
      Serial.println(raw);
      break;

    case 'l': {
      if (!isRudder(a)) { Serial.println(F("!! 'l' so vale para o leme")); changed = false; break; }
      int16_t rel = relativeToRest(a, raw);
      if (cal.invert) rel = -rel;
      if (rel > -MIN_TRAVEL) {
        Serial.println(F("!! curso pequeno demais ou lado trocado - use 0i e repita"));
        changed = false; break;
      }
      cal.minRel = rel;
      Serial.print(F(">> batente esquerdo = ")); Serial.println(rel);
      break;
    }

    case 'r': {
      int16_t rel = relativeToRest(a, raw);
      if (isRudder(a)) {
        if (cal.invert) rel = -rel;
        if (rel < MIN_TRAVEL) {
          Serial.println(F("!! curso pequeno demais ou lado trocado - use 0i e repita"));
          changed = false; break;
        }
      } else {
        // Freio: o sentido de acionamento e deduzido, sem passo de inversao.
        if (rel < 0) { cal.invert = 1; rel = -rel; }
        else         { cal.invert = 0; }
        if (rel < MIN_TRAVEL) {
          Serial.println(F("!! curso pequeno demais - o freio precisa de ~10 graus"));
          changed = false; break;
        }
      }
      cal.maxRel = rel;
      Serial.print(F(">> ")); Serial.print(axisName(a));
      Serial.print(isRudder(a) ? F(": batente direito = ") : F(": fundo = "));
      Serial.println(rel);
      break;
    }

    case 'i':
      cal.invert = !cal.invert;
      Serial.print(F(">> ")); Serial.print(axisName(a));
      Serial.print(F(": inversao ")); Serial.println(cal.invert ? F("sim") : F("nao"));
      break;

    case 'd':
      cal.deadzone = hasArg ? constrain(arg, 0, 64)
                            : (cal.deadzone == 0) ? 2 : (cal.deadzone == 2) ? 4
                            : (cal.deadzone == 4) ? 8 : 0;
      Serial.print(F(">> ")); Serial.print(axisName(a));
      Serial.print(F(": deadzone = ")); Serial.println(cal.deadzone);
      break;

    case 'x':
      cal.expo = hasArg ? constrain(arg, 0, 90) : (cal.expo + 15) % 60;
      Serial.print(F(">> ")); Serial.print(axisName(a));
      Serial.print(F(": expo = ")); Serial.print(cal.expo); Serial.println('%');
      break;

    default:
      changed = false;
      break;
  }

  if (changed) sendConfigLine(a);
}

void handleLine(char *line) {
  // prefixo numerico = comando de eixo
  if (line[0] >= '0' && line[0] <= '9') {
    uint8_t a = line[0] - '0';
    if (a >= AXIS_COUNT || line[1] == '\0') {
      Serial.println(F("!! eixo invalido (use 0=leme 1=freio esq 2=freio dir)"));
      return;
    }
    bool hasArg = (line[2] != '\0');
    handleAxisCommand(a, line[1], hasArg, hasArg ? atoi(line + 2) : 0);
    return;
  }

  switch (line[0]) {
    case 'w': case 'W': saveConfig(); break;

    case 'e': case 'E':
      loadDefaults();
      EEPROM.put(EEPROM_ADDR, cfg);
      Serial.println(F(">> EEPROM apagada, valores padrao restaurados"));
      sendAllConfig();
      break;

    case '?': printConfig();       sendAllConfig(); break;
    case '>': telemetry = true;    sendAllConfig(); break;
    case '<': telemetry = false;   break;

    case 's': case 'S': printMagnetStatus(); break;

    case 'p': case 'P':
      monitor = !monitor;
      Serial.println(monitor ? F(">> monitor ON") : F(">> monitor OFF"));
      break;

    default: break;
  }
}

// Acumula caracteres ate \n ou \r e entrega a linha completa. Se o Serial
// Monitor estiver em "sem fim de linha", o timeout abaixo executa mesmo assim.
void pumpSerial() {
  while (Serial.available()) {
    char c = Serial.read();
    lastCharMs = millis();
    if (c == '\n' || c == '\r') {
      if (cmdLen > 0) { cmdBuf[cmdLen] = '\0'; handleLine(cmdBuf); cmdLen = 0; }
    } else if (cmdLen < sizeof(cmdBuf) - 1) {
      cmdBuf[cmdLen++] = c;
    }
  }

  if (cmdLen > 0 && millis() - lastCharMs > 100) {
    cmdBuf[cmdLen] = '\0';
    handleLine(cmdBuf);
    cmdLen = 0;
  }
}

// -------------------------------------------------------------------- setup
void setup() {
  Serial.begin(115200);

  // Da tempo do mux e dos sensores sairem do proprio power-on antes de falar
  // com eles. Num plug a frio tudo energiza junto; sem esta folga o primeiro
  // acesso I2C pega o barramento num estado indefinido.
  delay(50);

  Wire.begin();
  // Pull-ups internos ficam LIGADOS: o barramento e todo 5V, e sem eles a lib
  // Wire trava com o barramento vazio (placa some da USB, LEDs acesos).
  Wire.setClock(I2C_CLOCK);

  // Sem isto a lib Wire espera o barramento liberar SEM LIMITE: um sensor
  // arrancado no meio de uma transacao segura o SDA em nivel baixo e o loop
  // principal morre junto com a USB. Com timeout o eixo vira "erro I2C"
  // (status 4) e o resto continua. Importa em uso real: os chicotes das
  // biqueiras flexionam, e um mau contato nao pode derrubar o pedal inteiro.
  Wire.setWireTimeout(3000, true);   // 3 ms, com reset do TWI ao estourar

  muxPresent = probe(MUX_ADDR);

  loadConfig();

  for (uint8_t a = 0; a < AXIS_COUNT; a++) {
    filtered[a] = 0.0f;
    lastRaw[a]  = 0;
    errors[a]   = 0;
    uint16_t raw;
    present[a] = readAngle(a, raw);
    if (present[a]) {
      lastRaw[a]  = raw;
      filtered[a] = applyExpo(a, normalize(a, relativeToRest(a, raw)));
    }
  }

  Joystick.setRzAxisRange(-RUDDER_RANGE, RUDDER_RANGE);
  Joystick.setXAxisRange(0, BRAKE_RANGE);
  Joystick.setYAxisRange(0, BRAKE_RANGE);
  Joystick.begin(false);          // envio manual, para controlar a taxa
  for (uint8_t a = 0; a < AXIS_COUNT; a++) pushToHid(a);
  Joystick.sendState();
}

// --------------------------------------------------------------------- loop
void loop() {
  uint32_t nowUs = micros();
  if (nowUs - lastUpdate < UPDATE_INTERVAL_US) return;
  lastUpdate = nowUs;

  // Round-robin: um sensor por tick de 1 ms -> 333 Hz por eixo, de sobra para
  // um pedal e sem estourar o orcamento de tempo do barramento.
  uint8_t a = rrChannel;
  rrChannel = (rrChannel + 1) % AXIS_COUNT;

  if (present[a]) {
    uint16_t raw;
    if (readAngle(a, raw)) {
      errors[a] = 0;
      lastRaw[a] = raw;

      float target = applyExpo(a, normalize(a, relativeToRest(a, raw)));
      filtered[a] += EMA_ALPHA * (target - filtered[a]);

      pushToHid(a);
      Joystick.sendState();
    } else if (errors[a] < 255) {
      // Falha de leitura: segura o ultimo valor em vez de mandar lixo ao sim.
      if (++errors[a] == 60) {
        Serial.print(F("ERRO: sem resposta no eixo ")); Serial.print(a);
        Serial.print(' '); Serial.println(axisName(a));
      }
    }
  }

  pumpSerial();

  uint32_t nowMs = millis();

  // Telemetria so quando alguem abriu a porta (evita encher o buffer CDC).
  if (telemetry && Serial && nowMs - lastTelem >= TELEM_INTERVAL_MS) {
    lastTelem = nowMs;
    sendTelemetry();
  }

  if (monitor && nowMs - lastPrint >= PRINT_INTERVAL_MS) {
    lastPrint = nowMs;
    for (uint8_t i = 0; i < AXIS_COUNT; i++) {
      Serial.print(axisName(i));
      Serial.print(F(" raw="));  Serial.print(lastRaw[i]);
      Serial.print(F(" ang="));  Serial.print(relativeToRest(i, lastRaw[i]) * 360.0f / 4096.0f, 2);
      Serial.print(F("deg val=")); Serial.print(hidValue(i));
      Serial.print(i == AXIS_COUNT - 1 ? '\n' : '\t');
    }
  }
}

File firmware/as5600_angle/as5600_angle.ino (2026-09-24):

/*
 * AS5600 - leitura de angulo com Arduino Pro Micro (ATmega32U4)
 *
 * Ligacao (Pro Micro):
 *   AS5600 SDA -> pino 2  (D2 / SDA)
 *   AS5600 SCL -> pino 3  (D3 / SCL)
 *   AS5600 VCC -> VCC     (5V - ver nota abaixo)
 *   AS5600 GND -> GND
 *   AS5600 DIR -> GND     (sentido horario = angulo crescente)
 *
 * TENSAO: tudo em 5V, sem regulador e sem conversor de nivel. O AS5600 tem
 * dois modos de alimentacao - VDD5V (4,5 a 5,5V, com LDO interno) ou VDD3V3
 * (3,0 a 3,6V). Com modulos da variante 5V o barramento inteiro roda no VCC
 * do Pro Micro. Confirme qual e o seu antes de ligar: num modulo 3,3V os 5V
 * passam do limite e queimam o sensor.
 *
 * Ima: diametral (magnetizado de lado a lado), 6x2.5mm ou 6x3mm,
 * centrado no eixo, a ~0.5-3mm da face marcada do chip.
 *
 * Saida no Serial Monitor (115200): angulo bruto, em graus e acumulado
 * (multivoltas), mais o status do ima.
 */

#include <Wire.h>

// ---------------------------------------------------------------- constantes
static const uint8_t AS5600_ADDR       = 0x36;

static const uint8_t REG_STATUS        = 0x0B;  // MH / ML / MD
static const uint8_t REG_RAW_ANGLE_H   = 0x0C;  // 12 bits, sem filtro de zero
static const uint8_t REG_ANGLE_H       = 0x0E;  // 12 bits, com ZPOS/MPOS
static const uint8_t REG_AGC           = 0x1B;
static const uint8_t REG_MAGNITUDE_H   = 0x1C;

static const uint8_t STATUS_MD         = 0x20;  // ima detectado
static const uint8_t STATUS_ML         = 0x10;  // ima muito fraco / longe
static const uint8_t STATUS_MH         = 0x08;  // ima muito forte / perto

static const float   COUNTS_TO_DEG     = 360.0f / 4096.0f;
static const uint16_t PRINT_INTERVAL_MS = 100;

// ------------------------------------------------------------------ estado
int16_t  lastRaw       = 0;      // ultima leitura bruta (0..4095)
int32_t  turns         = 0;      // voltas completas acumuladas
uint16_t zeroOffset    = 0;      // zero por software (comando 'z')
uint32_t lastPrint     = 0;

// -------------------------------------------------------------- I2C helpers
// Le um registrador de 8 bits. Retorna false em caso de erro de barramento.
bool readReg8(uint8_t reg, uint8_t &value) {
  Wire.beginTransmission(AS5600_ADDR);
  Wire.write(reg);
  if (Wire.endTransmission(false) != 0) return false;   // repeated start

  if (Wire.requestFrom((uint8_t)AS5600_ADDR, (uint8_t)1) != 1) return false;
  value = Wire.read();
  return true;
}

// Le um par de registradores (high, high+1) e devolve os 12 bits uteis.
bool readReg12(uint8_t regHigh, uint16_t &value) {
  Wire.beginTransmission(AS5600_ADDR);
  Wire.write(regHigh);
  if (Wire.endTransmission(false) != 0) return false;

  if (Wire.requestFrom((uint8_t)AS5600_ADDR, (uint8_t)2) != 2) return false;
  uint8_t hi = Wire.read();
  uint8_t lo = Wire.read();
  value = (((uint16_t)hi << 8) | lo) & 0x0FFF;
  return true;
}

// ------------------------------------------------------------------ dominio
// Acumula voltas detectando o salto 4095 -> 0 (e vice-versa).
void updateTurns(int16_t raw) {
  int16_t delta = raw - lastRaw;
  if (delta > 2048)       turns--;   // passou de 0 para 4095 (sentido negativo)
  else if (delta < -2048) turns++;   // passou de 4095 para 0 (sentido positivo)
  lastRaw = raw;
}

// Angulo 0..360 relativo ao zero por software.
float angleDeg(uint16_t raw) {
  int16_t rel = (int16_t)raw - (int16_t)zeroOffset;
  if (rel < 0) rel += 4096;
  return rel * COUNTS_TO_DEG;
}

// Angulo continuo (pode passar de 360 ou ficar negativo).
float totalAngleDeg(uint16_t raw) {
  return turns * 360.0f + raw * COUNTS_TO_DEG - zeroOffset * COUNTS_TO_DEG;
}

void printStatus() {
  uint8_t status = 0, agc = 0;
  uint16_t magnitude = 0;

  if (!readReg8(REG_STATUS, status)) {
    Serial.println(F("STATUS: falha na leitura I2C"));
    return;
  }
  readReg8(REG_AGC, agc);
  readReg12(REG_MAGNITUDE_H, magnitude);

  Serial.print(F("STATUS: "));
  if (!(status & STATUS_MD))     Serial.print(F("SEM IMA detectado"));
  else if (status & STATUS_ML)   Serial.print(F("ima FRACO (afaste menos / aproxime)"));
  else if (status & STATUS_MH)   Serial.print(F("ima FORTE (afaste um pouco)"));
  else                           Serial.print(F("ima OK"));

  Serial.print(F(" | AGC="));       Serial.print(agc);
  Serial.print(F(" | MAG="));       Serial.print(magnitude);
  Serial.println();
}

// -------------------------------------------------------------------- setup
void setup() {
  Serial.begin(115200);
  while (!Serial && millis() < 3000) { /* Pro Micro: espera USB, com timeout */ }

  Wire.begin();
  // Pull-ups internos do ATmega32U4 ficam LIGADOS (padrao do Wire.begin).
  // O barramento todo e 5V, entao eles nao agridem o AS5600 e ainda mantem
  // SDA/SCL definidos quando nenhum sensor esta ligado. Sem eles a lib Wire
  // do AVR trava esperando um nivel alto que nunca chega, e a placa some da
  // USB com os LEDs acesos.

  Wire.setClock(400000);   // fast mode; use 100000 se o cabo for longo

  Serial.println(F("=== AS5600 - leitor de angulo ==="));
  Serial.println(F("Comandos: 'z' zera no angulo atual | 's' status do ima"));

  printStatus();

  uint16_t raw;
  if (readReg12(REG_RAW_ANGLE_H, raw)) {
    lastRaw = raw;
  } else {
    Serial.println(F("ERRO: AS5600 nao respondeu. Confira SDA=2, SCL=3, GND e alimentacao."));
  }
}

// --------------------------------------------------------------------- loop
void loop() {
  uint16_t raw;
  if (!readReg12(REG_RAW_ANGLE_H, raw)) {
    Serial.println(F("ERRO de leitura I2C"));
    delay(500);
    return;
  }

  updateTurns((int16_t)raw);

  // comandos pelo Serial Monitor
  while (Serial.available()) {
    char c = Serial.read();
    if (c == 'z' || c == 'Z') {
      zeroOffset = raw;
      turns = 0;
      Serial.println(F(">> zero ajustado na posicao atual"));
    } else if (c == 's' || c == 'S') {
      printStatus();
    }
  }

  uint32_t now = millis();
  if (now - lastPrint >= PRINT_INTERVAL_MS) {
    lastPrint = now;

    Serial.print(F("raw="));    Serial.print(raw);
    Serial.print(F("\tang="));  Serial.print(angleDeg(raw), 2);
    Serial.print(F(" deg\tacum=")); Serial.print(totalAngleDeg(raw), 2);
    Serial.print(F(" deg\tvoltas=")); Serial.println(turns);
  }
}

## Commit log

2026-09-07 Open Rudder: CAD, firmware de 3 eixos e calibrador web
    Rudder pedal magnético com sensor AS5600 sem contato.
    - open_rudder.scad: CAD paramétrico (centragem magnética, amortecedor
    eddy, peças imprimíveis).
    - firmware/open_rudder: Pro Micro como joystick USB HID. Leme no eixo Rz
    e dois freios de biqueira em X/Y, lidos por 3x AS5600 atrás de um
    TCA9548A (o endereço 0x36 do AS5600 é fixo, então os sensores não
    coexistem no mesmo barramento). Round-robin de 1 kHz = 333 Hz por eixo,
    calibração por eixo na EEPROM, filtro EMA e curva expo.
    Sem o mux ligado, cai automaticamente para o modo de 1 sensor.
    - web/calibrador.html: calibra e visualiza os eixos pela Web Serial,
    sem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
    [magnus_s1.scad, magnus_s1.stl, open_rudder.scad]
2026-09-07 hardware: diagramas como SVG de verdade, não inline no HTML
    Os desenhos existiam só embutidos no diagrama.html — o da perfurada nem
    markup era, saía de um gerador JavaScript em tempo de execução. Nada
    disso o GitHub renderiza, o Inkscape abre ou o diff mostra.
    - ligacao.svg: extraído do HTML, com as var() do CSS trocadas pelos
    valores literais (fora do HTML elas não resolvem) e os comentários
    normalizados — XML proíbe '--' dentro de comentário, e como <img> o
    SVG é parseado como XML, não como HTML.
    - perfurada.svg: agora vem de gerar_perfurada.py, em mm, para imprimir
    1:1 como gabarito.
    - diagrama.html vira só a folha imprimível e embute os dois por <img>.
    - Removi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
2026-09-07 Descreve o projeto certo: rudder pendular, não o MAGNUS
    O README vinha de outro projeto — barra central, anel de centragem
    magnética, amortecedor eddy e o manche S1 não são deste pedal. O
    Open Rudder é um rudder pendular; a mecânica dele ainda não está
    documentada e ficou marcada como tal, em vez de descrita por engano.
    Reescrito em torno do que existe e foi verificado: eixos HID, ligação
    com o TCA9548A, firmware, calibração por Web Serial e as restrições
    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
    [magnus_s1.scad, magnus_s1.stl, open_rudder.scad]
2026-09-07 Documenta a mecânica: ímã na ponta da barra, retorno por mola
    Barra em rolamentos com o ímã diametral coaxial na ponta, AS5600 fixo
    de frente. Retorno por mola comprimida no acionamento — a posição de
    repouso da mola é o zero elétrico, o que torna o re-zero barato se ela
    ceder: os batentes são relativos ao zero e continuam válidos.
2026-09-07 Página inicial para o GitHub Pages
    Junta o calibrador e o esquema elétrico numa porta de entrada. Servido
    por HTTPS, que é contexto seguro: a Web Serial funciona direto no site,
    sem precisar subir o servidor local do servir.bat.
2026-09-07 Aponta os READMEs para o site e corrige texto do esquema
    O bloco do canal 0 no diagrama ainda dizia 'no eixo Ø8 da rudder bar',
    resto da barra central do outro projeto — agora descreve a ponta da
    barra em rolamentos, que é o arranjo deste pedal.
    Com o site em HTTPS o servir.bat deixa de ser obrigatório e passa a ser
    só o caminho offline.
2026-09-07 hardware: terceira folha com o chicote do sensor
    Desenho do conjunto sensor-cabo-conector com a tabela de ligação via a
    via, incluindo coluna em branco para anotar a cor real do cabo: o
    UL2464 não segue convenção de cores e a troca de SDA com SCL é o erro
    fácil de cometer com a capa já removida.
    Registra as duas decisões que decidem a durabilidade: solda no lado do
    sensor com conector só no lado da placa (a ponta que flexiona é a que
    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
2026-09-08 Corrige a tensão de alimentação: 5 V direto, sem regulador
    Eu vinha afirmando que o AS5600 é um chip de 3,3 V e que nada no
    barramento podia ver 5 V. Está errado: o datasheet especifica dois
    modos — VDD5V de 4,5 a 5,5 V com LDO interno, ou VDD3V3 de 3,0 a 3,6 V.
    Com módulos de 5 V, o barramento inteiro roda no VCC do Pro Micro e o
    AMS1117 deixa de ser necessário (o TCA9548A aceita até 5,5 V).
    O trilho passa a se chamar VCC no esquema, na perfurada e no chicote.
    O bloco do AMS1117 continua reservado no layout, agora rotulado como
    exclusivo da variante 3,3 V dos módulos — nela, 5 V ultrapassa os 3,6 V
    e queima o sensor, então a distinção precisa ficar visível.
2026-09-24 firmware: barramento todo em 5 V e TWI que não trava
    Os dois sketches desligavam os pull-ups internos do ATmega32U4, herança da
    ideia de que o AS5600 seria 3,3 V. Com módulos da variante VDD5V o barramento
    inteiro roda no VCC do Pro Micro, e sem os pull-ups a lib Wire fica esperando
    um nível alto que nunca chega: a placa some da USB com os LEDs acesos.
    Acrescenta Wire.setWireTimeout(3000, true) e uma folga de 50 ms antes do
    primeiro acesso I2C. Sem o timeout, um sensor arrancado no meio de uma
    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
2026-09-24 hardware: folha do layout na placa de tiras
    Alternativa à placa perfurada lisa, para PCB estilo protoboard: linhas
    horizontais de 5 furos separadas por dois trilhos verticais centrais.
    Os trilhos viram GND (coluna F) e VCC (coluna G), e os três conectores dos
    sensores montam a cavalo sobre eles — os dois pinos do meio caem direto na
    alimentação. Isso elimina os seis jumpers de força dos sensores; Pro Micro e
    mux ficam com um jumper de um furo cada, e só o VIN do mux precisa pular um
    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
2026-09-26 hardware: caixa impressa da placa de controle
    Duas peças em PETG, sem parafuso prendendo a placa: ela desce na bandeja e
    pousa num ressalto corrido, e as nervuras da tampa a seguram de cima. Placa de
    tiras não tem furo de fixação, e furar depois de montada é onde se corta uma
    trilha sem perceber.
    Saídas: rasgo corrido na tampa para os três chicotes (o JST-XH é de entrada
    vertical, então o cabo já sai para cima), recorte do USB-C na parede da ponta,
    furo para o interruptor de reset e dois furos de fixação a 80 mm para castanha
    de 2020, escareados pela face interna.
    Todas as cotas da placa e das posições dos conectores são parâmetros no topo,
    inclusive uma folga de impressão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
    [case.scad, case_base.stl, case_tampa.stl]
2026-09-26 Página única: guia de montagem completo na raiz
    O index.html deixa de ser um índice de links e passa a carregar o projeto
    inteiro, na ordem em que a montagem acontece: especificações, lista de
    material, esquema elétrico, placa, chicote, caixa, mecânica, firmware,
    calibração e referência dos comandos da serial.
    É documentação de produto, não de projeto: diz o que fazer, não por que foi
    decidido assim. As justificativas continuam onde servem — nos comentários dos
    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
2026-09-26 Fotos do pedal montado na página
    Abertura com a vista frontal e uma seção com a de cima e a lateral, entre a
    mecânica e o firmware — é onde o leitor acabou de entender como a coisa
    funciona e quer ver o resultado.
    As fotos passam por fotos/tratar.py em vez de irem direto do celular. O pedal
    é todo preto sobre piso de madeira claro, e isso pede dois ajustes que não são
    óbvios: curva de gama para abrir a faixa baixa (contraste global faria o
    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
